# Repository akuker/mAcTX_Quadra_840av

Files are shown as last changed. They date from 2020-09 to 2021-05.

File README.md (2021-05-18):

# mAcTX_Quadra_840av
Adapter board to allow an ATX Power Supply to be used with a Quadra 840av

Mouser Bill of Materials: https://www.mouser.com/ProjectManager/ProjectDetail.aspx?AccessID=3659aac31a

Schematic: [mAcTX_Quadra_840av.pdf](mAcTX_Quadra_840av/mAcTX_Quadra_840av_sch.pdf)

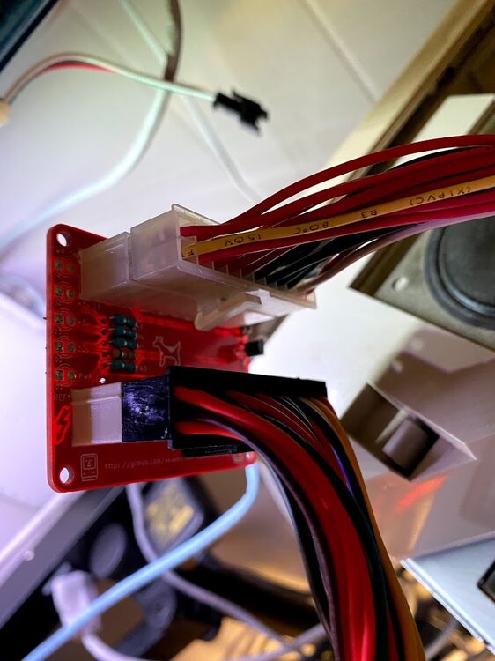
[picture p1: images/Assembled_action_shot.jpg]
Action shot 1

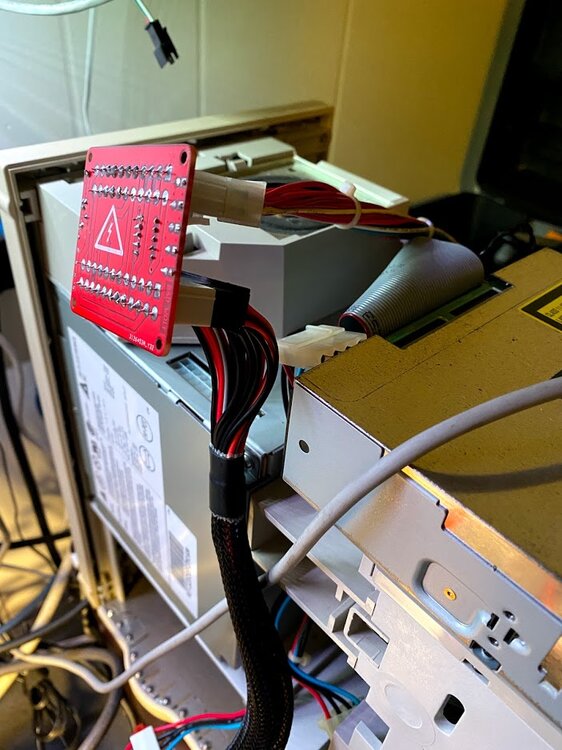
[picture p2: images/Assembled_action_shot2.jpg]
Action shot 2

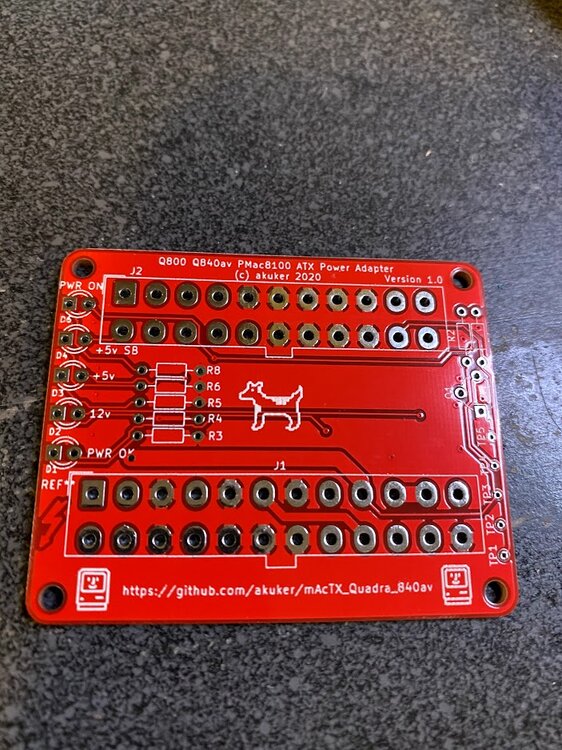
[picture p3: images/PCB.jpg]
Circuit Board

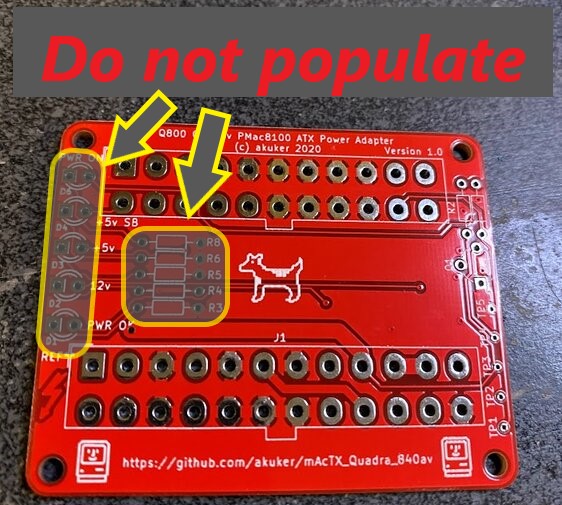
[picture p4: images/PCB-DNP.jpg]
Circuit Board - DNP


Note: I used a 2N3904 NPN transistor for the soft power circuit. Others may work as well.

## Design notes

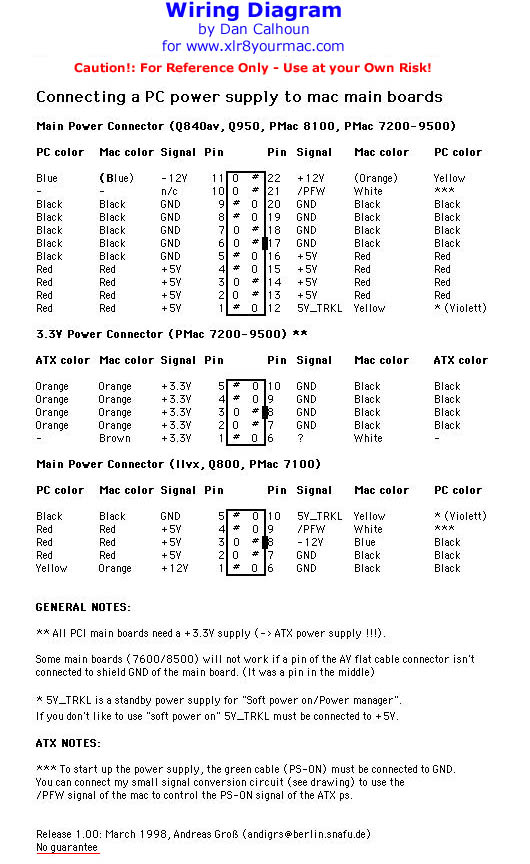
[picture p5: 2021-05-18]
images/PC-MAC_PS_pinouts.jpg

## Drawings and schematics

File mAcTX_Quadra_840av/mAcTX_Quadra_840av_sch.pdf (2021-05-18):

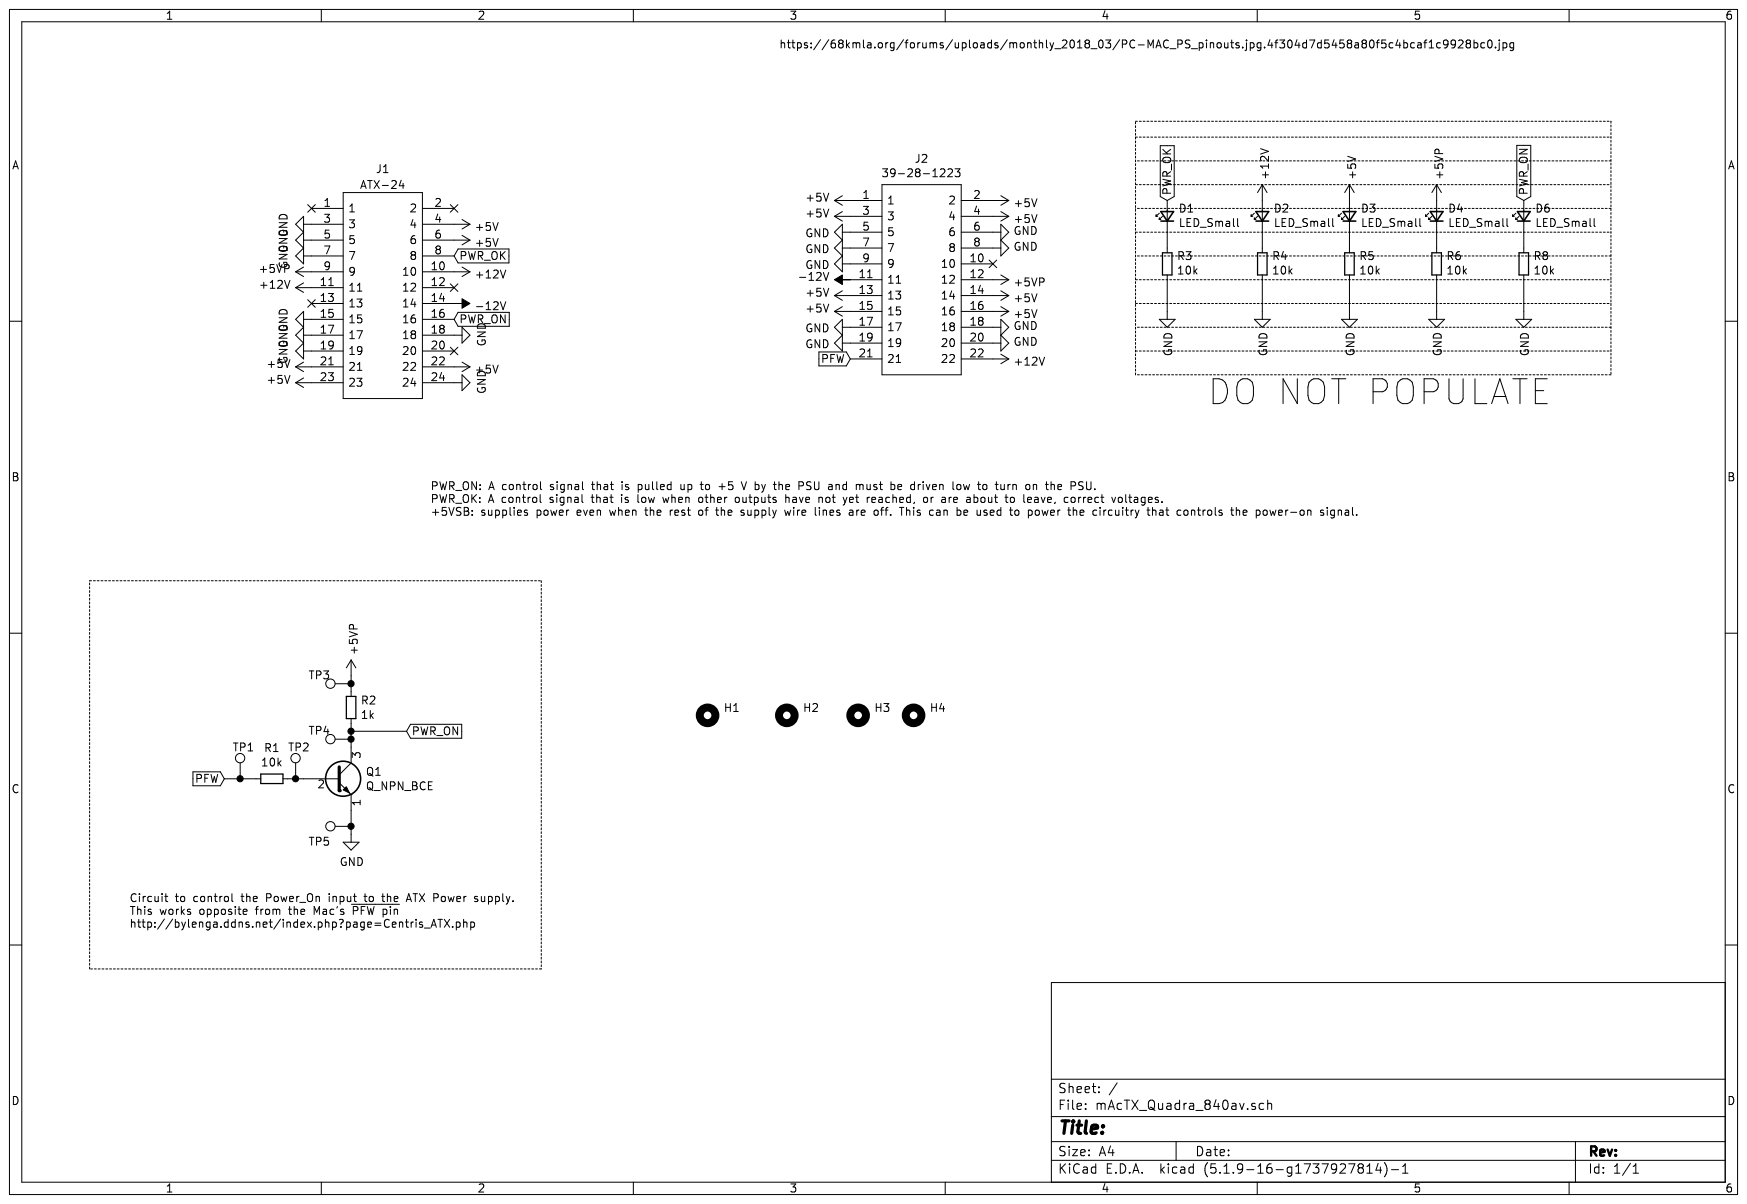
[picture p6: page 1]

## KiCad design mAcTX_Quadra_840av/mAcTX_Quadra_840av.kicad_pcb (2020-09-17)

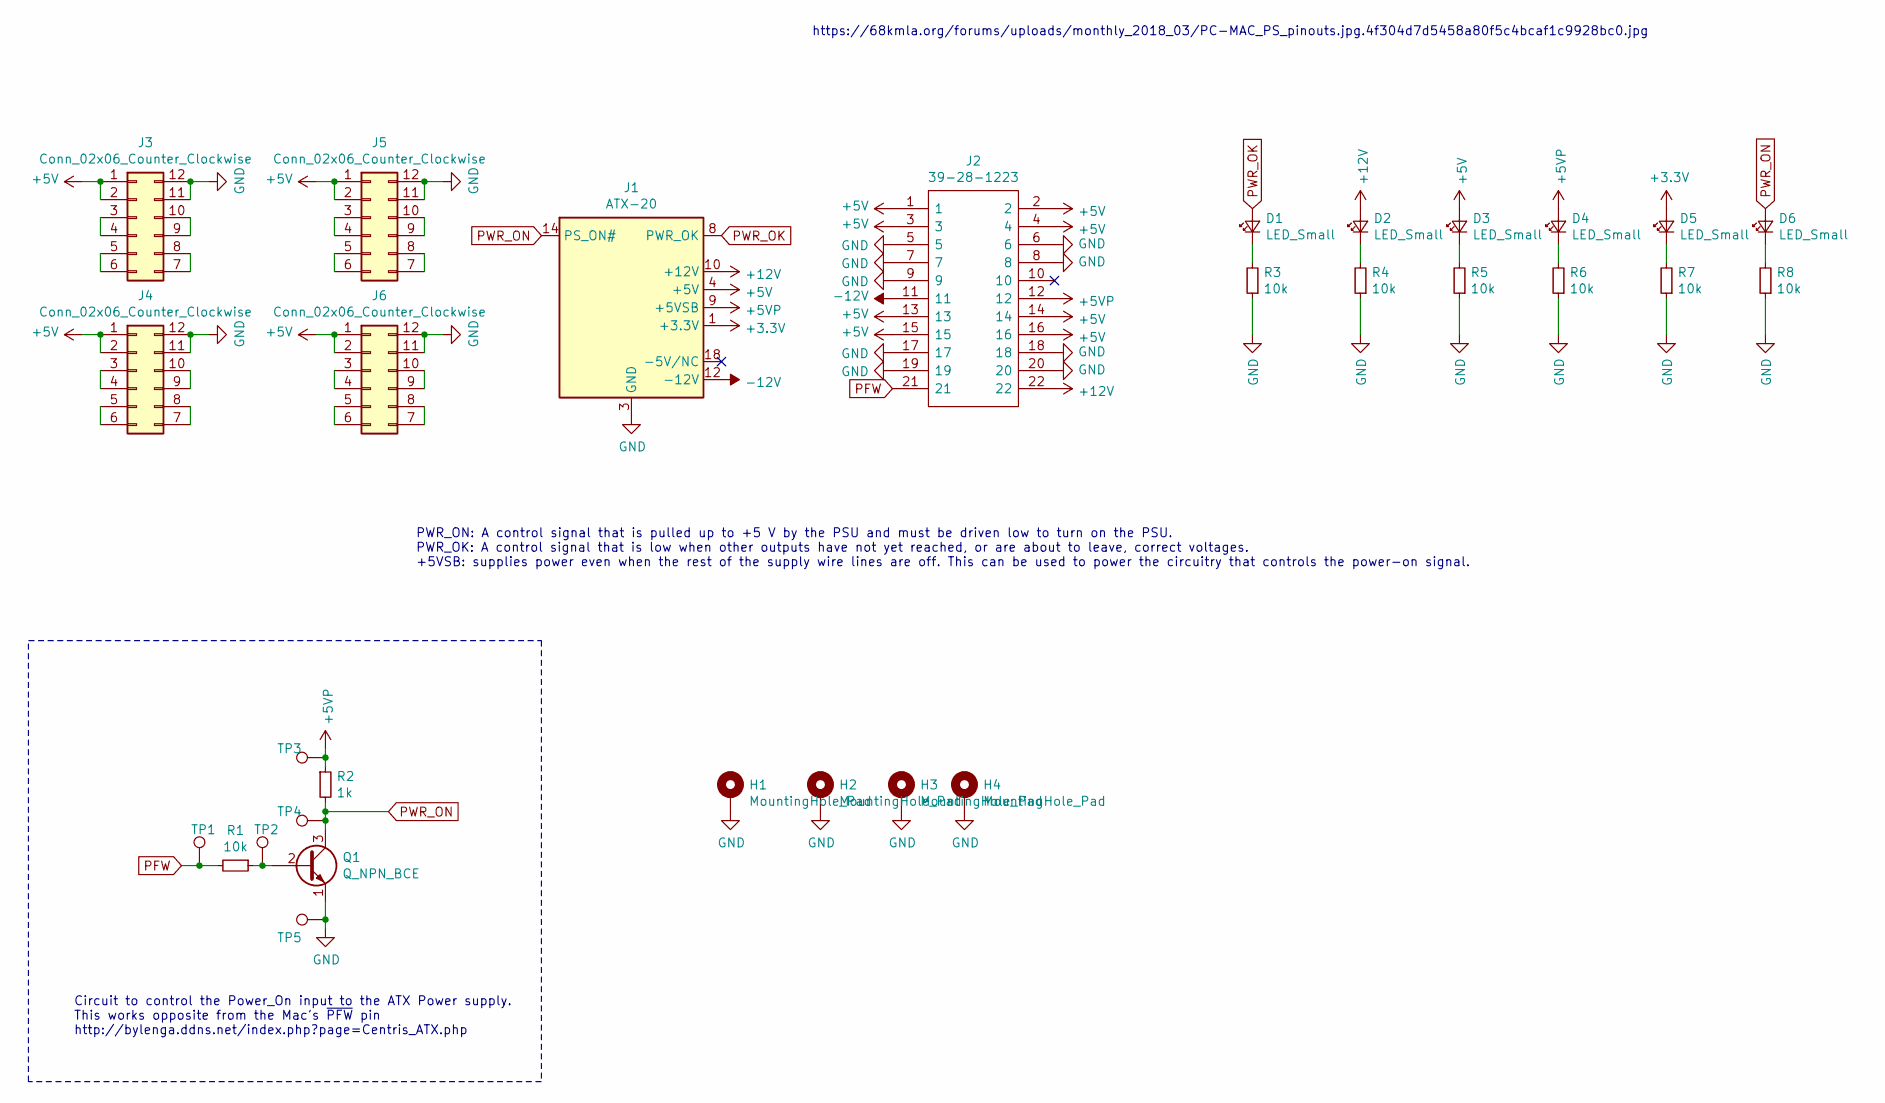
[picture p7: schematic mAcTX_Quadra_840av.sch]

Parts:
D1, D2, D3, D4, D5, D6: LED_Small; LED_D3.0mm
H1, H2, H3, H4: MountingHole_Pad; MountingHole_2.7mm_M2.5_Pad
J1: ATX-20; Molex_Mini-Fit_Jr_5566-20A_2x10_P4.20mm_Vertical
J2: 39-28-1223; SHDR22W125P420_2X11_4740X960X1310P; Mouser Part Number 538-39-28-1223
J3, J4, J5, J6: Conn_02x06_Counter_Clockwise; PinHeader_2x06_P2.54mm_Vertical
Q1: Q_NPN_BCE; TO-92
R1, R3, R4, R5, R6, R7, R8: 10k; R_Axial_DIN0204_L3.6mm_D1.6mm_P7.62mm_Horizontal
R2: 1k; R_Axial_DIN0204_L3.6mm_D1.6mm_P7.62mm_Horizontal
TP1, TP2, TP3, TP4, TP5: TestPoint; TestPoint_THTPad_D1.0mm_Drill0.5mm

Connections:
+3V3: D5.2 (A), J1.1 (+3.3V), J1.2 (+3.3V), J1.11 (+3.3V)
+5V: D3.2 (A), J1.4 (+5V), J1.6 (+5V), J1.19 (+5V), J1.20 (+5V), J2.1, J2.2, J2.3, J2.4, J2.13, J2.14, J2.15, J2.16, J3.1, J3.2, J4.1, J4.2, J5.1, J5.2, J6.1, J6.2
+5VP: D4.2 (A), J1.9 (+5VSB), J2.12, R2.1, TP3.1
+12V: D2.2 (A), J1.10 (+12V), J2.22
-12V: J1.12 (-12V), J2.11
GND: H1.1, H2.1, H3.1, H4.1, J1.3 (GND), J1.5 (GND), J1.7 (GND), J1.13 (GND), J1.15 (GND), J1.16 (GND), J1.17 (GND), J2.5, J2.6, J2.7, J2.8, J2.9, J2.17, J2.18, J2.19, J2.20, J3.11, J3.12, J4.11, J4.12, J5.11, J5.12, J6.11, J6.12, Q1.1 (E), R3.1, R4.1, R5.1, R6.1, R7.1, R8.1, TP5.1
unnamed: D1.1 (K), R3.2
unnamed: D2.1 (K), R4.2
unnamed: D3.1 (K), R5.2
unnamed: D4.1 (K), R6.2
unnamed: D5.1 (K), R7.2
unnamed: D6.1 (K), R8.2
unnamed: J3.3, J3.4
unnamed: J3.5, J3.6
unnamed: J3.7, J3.8
unnamed: J3.9, J3.10
unnamed: J4.3, J4.4
unnamed: J4.5, J4.6
unnamed: J4.7, J4.8
unnamed: J4.9, J4.10
unnamed: J5.3, J5.4
unnamed: J5.5, J5.6
unnamed: J5.7, J5.8
unnamed: J5.9, J5.10
unnamed: J6.3, J6.4
unnamed: J6.5, J6.6
unnamed: J6.7, J6.8
unnamed: J6.9, J6.10
unnamed: Q1.2 (B), R1.1, TP2.1
PFW: J2.21, R1.2, TP1.1
PWR_OK: D1.2 (A), J1.8 (PWR_OK)
PWR_ON: D6.2 (A), J1.14 (PS_ON#), Q1.3 (C), R2.2, TP4.1

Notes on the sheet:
https://68kmla.org/forums/uploads/monthly_2018_03/PC-MAC_PS_pinouts.jpg.4f304d7d5458a80f5c4bcaf1c9928bc0.jpg
PWR_ON: A control signal that is pulled up to +5 V by the PSU and must be driven low to turn on the PSU. PWR_OK: A control signal that is low when other outputs have not yet reached, or are about to leave, correct voltages. +5VSB: supplies power even when the rest of the supply wire lines are off. 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
Circuit to control the Power_On input to the ATX Power supply. This works opposite from the Mac's ~PFW pin http://bylenga.ddns.net/index.php?page=Centris_ATX.php

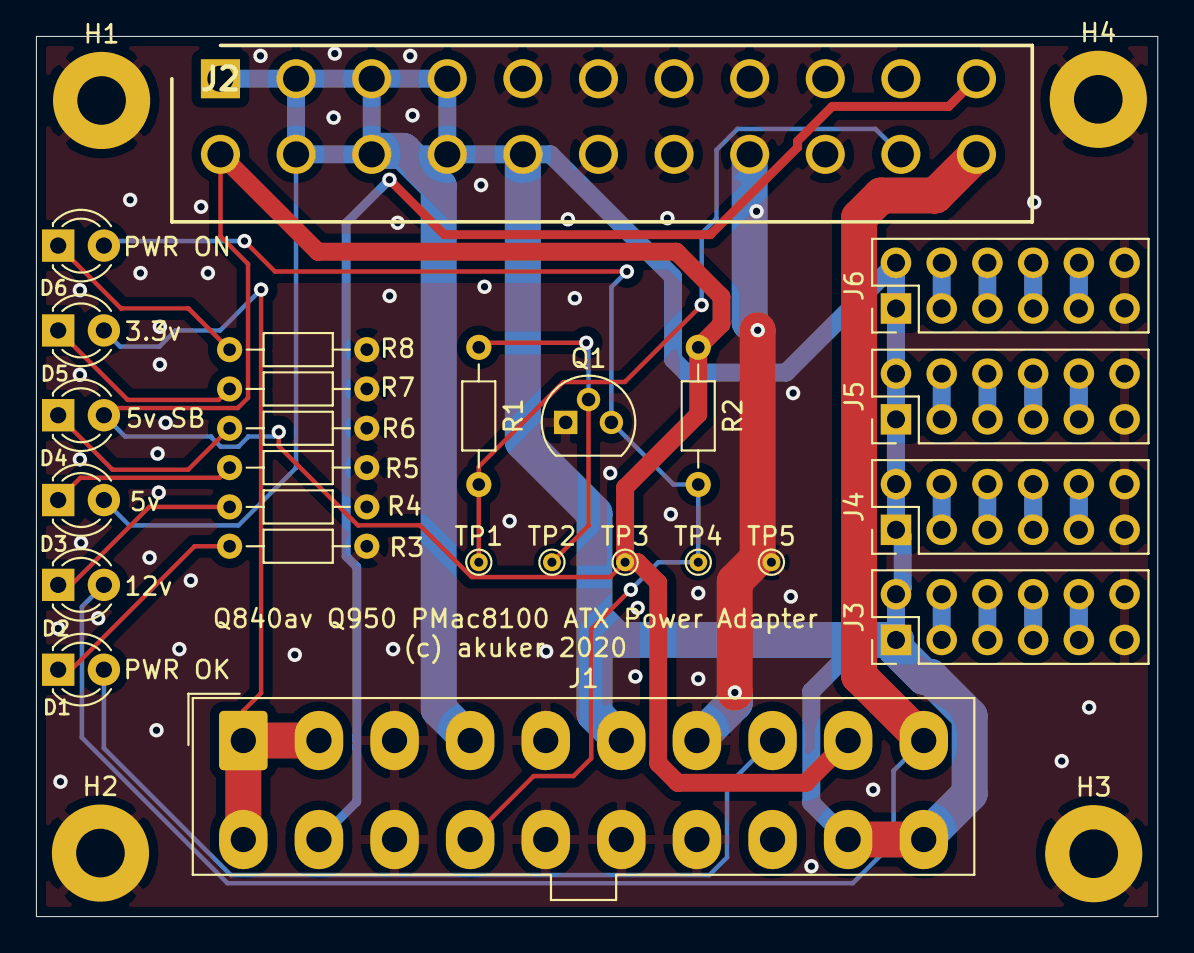
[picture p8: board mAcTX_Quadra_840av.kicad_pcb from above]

Board: 2 copper layers, 62.3 x 48.9 mm, 30 parts (0 on the bottom side), 32 nets.

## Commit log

2020-09-17 Initial draft
    Initial draft of a ATX -> Quadra 840av power supply adapter
    [asdf-B_Cu.gbr, asdf-B_Mask.gbr, asdf-B_Paste.gbr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]
2020-09-17 Rename file
    [mAcTX_Quadra_840av.kicad_pcb, mAcTX_Quadra_840av.sch]
2020-09-17 Updated for BadGoldEagle's comments
    [asdf-B_Cu.gbr, asdf-B_Mask.gbr, asdf-B_Paste.gbr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]
2021-05-18 Updated schematic to show which parts should not be populated
    [mAcTX_Quadra_840av.sch]
